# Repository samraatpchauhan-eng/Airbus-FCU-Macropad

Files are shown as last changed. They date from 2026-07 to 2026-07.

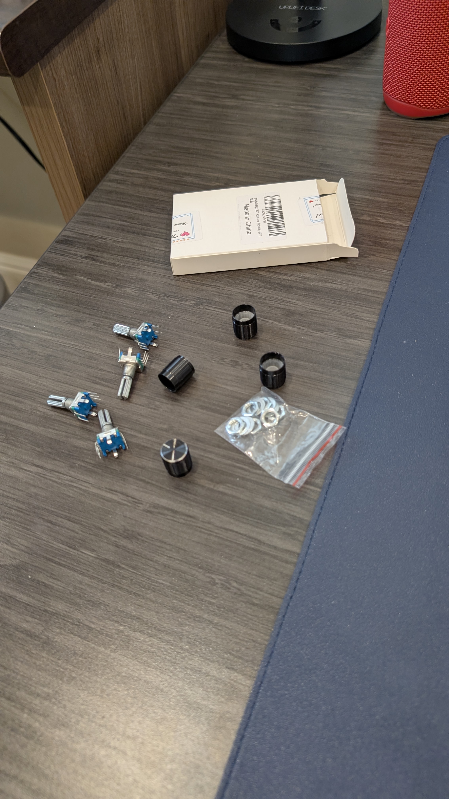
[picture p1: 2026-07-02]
Assets/PXL_20260702_192811092.jpg

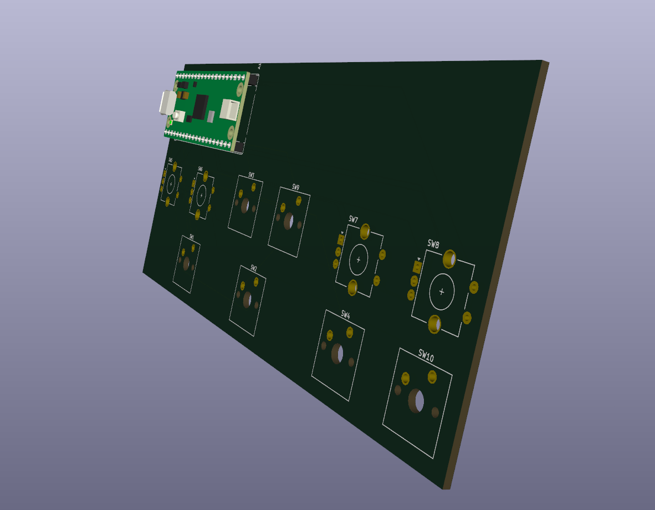
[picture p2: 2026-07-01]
Assets/Screenshot 2026-07-01 002633.png

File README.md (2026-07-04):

# Airbus FCU-Macropad

Airbus-FCU is a scaled replica of the Flight Control Unit found on Airbus aircraft, such as the Airbus A320. It is powered by a **RP Pico 1**, which has the rp2040 chip. It is used to make workflows more efficient, and to convert your desktop into a virtual cockpit! I designed it because as an aviation enthusiast, I wanted to have the ability to integrate aspects of flight and aviation in my day to day life, and I thought that instead of using a generic macropad, why not have it look like the FCU found on the airbus a320!

## Features:
* **Custom Layout:**  6 Cherry MX switches and 4 ec11 switched rotary encoders (10 Keys Total).
* **Quad Encoders:** Quad EC11 Encoders for precise, media adjustments (like brightness, zooming, or volume).
* **Realistic Design:** Engineered with a precise layout matching the real FCU found on the A320, and coordinating most commonly used inputs for an easy to use layout.
* **RP2040 Power:** Driven by the RP2040 chip for rapid response times and effortless flashing.

---

## CAD Model & Case Assembly
Everything fits together precisely using a layered enclosure design. The case includes structural mounting points for the PCB, plates, and components to ensure zero deck-flex during heavy use. Please note the keycaps used in these renders are generic .STEP models downloaded from the internet, and any standard MX keycap should work.

### Case Assembly & Fitment
*A 3D CAD visualization highlighting how the PCB, switches, encoders, and structural enclosure layers interface together seamlessly.*

Airbus-FCU-Case_2026-Jul-02_07-37-07PM-000_CustomizedView3551822146

Airbus-FCU-Case_2026-Jul-02_07-30-18PM-000_CustomizedView15151844348

---

## PCB Design
The underlying electronics were engineered in KiCad. The board features clean routing paths optimized for the RP2040 pin configurations and a direct connection layout to handle both the key switches and rotary encoders.

### Schematic Design
*The circuit schematic mapping the switch routing, and quad encoder connections to the microcontroller.*



### PCB Layout Architecture
*The routed printed circuit board design detailing trace paths, footprints, and physical alignment.*



---

## How to Flash
1. Disconnect the USB cable from the Flight Pad.
2. Press and hold the physical **BOOT** button on the RP2040 controller board.
3. Reconnect the USB cable while holding the button, then release it.
4. A virtual drive named will mount to your operating system.
5. Drag and drop the `airbus_fcu_macropad_default.uf2` binary file directly onto the root of the drive.
6. The device will automatically flash, reboot, and initialize as an operational HID keyboard device.

---

## AI Attribution Note
**Please Note that AI was utilized for some basic project planning and debugging of the Keyboard.JSON, and Keymap.C files in VS.Code**

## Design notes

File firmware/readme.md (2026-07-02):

# airbus_fcu_macropad

*A short description of the keyboard/project*

* Keyboard Maintainer: [Samraat Chauhan](https://github.com/samraatpchauhan-eng)
* Hardware Supported: *The PCBs, controllers supported*
* Hardware Availability: *Links to where you can find this hardware*

Make example for this keyboard (after setting up your build environment):

    make airbus_fcu_macropad:default

Flashing example for this keyboard:

    make airbus_fcu_macropad:default:flash

See the [build environment setup](https://docs.qmk.fm/#/getting_started_build_tools) and the [make instructions](https://docs.qmk.fm/#/getting_started_make_guide) for more information. Brand new to QMK? Start with our [Complete Newbs Guide](https://docs.qmk.fm/#/newbs).

## Bootloader

Enter the bootloader in 3 ways:

* **Bootmagic reset**: Hold down the key at (0,0) in the matrix (usually the top left key or Escape) and plug in the keyboard
* **Physical reset button**: Briefly press the button on the back of the PCB - some may have pads you must short instead
* **Keycode in layout**: Press the key mapped to `QK_BOOT` if it is available

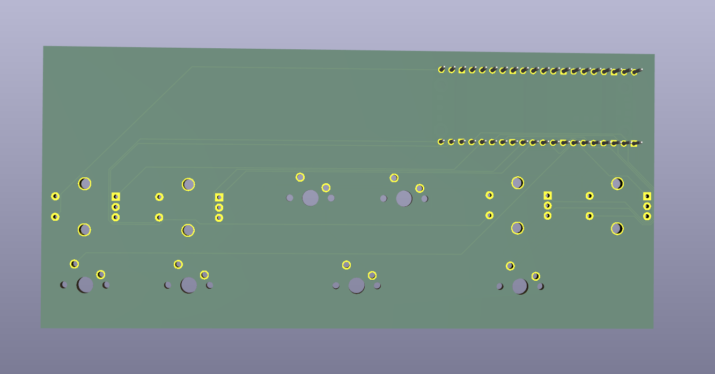
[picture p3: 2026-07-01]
Assets/Screenshot 2026-07-01 002709.png

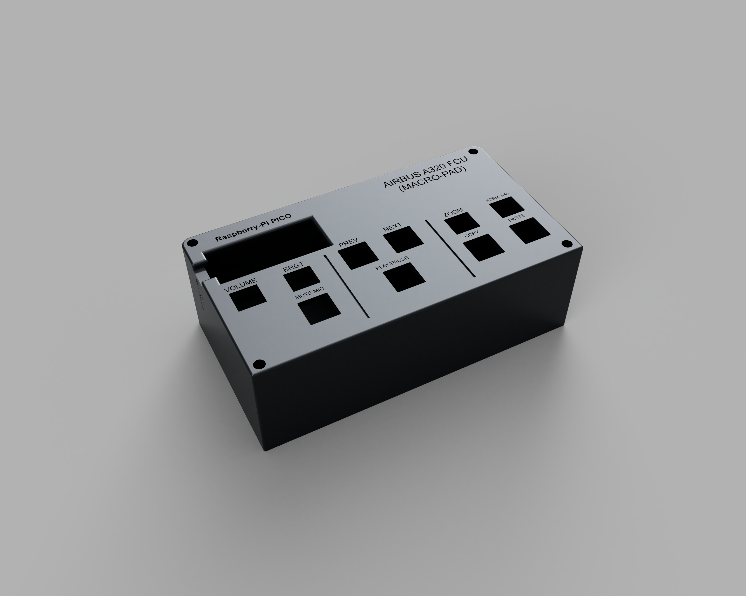
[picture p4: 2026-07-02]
Assets/Airbus-FCU-Case_2026-Jul-02_07-24-20PM-000_CustomizedView7984582045.png

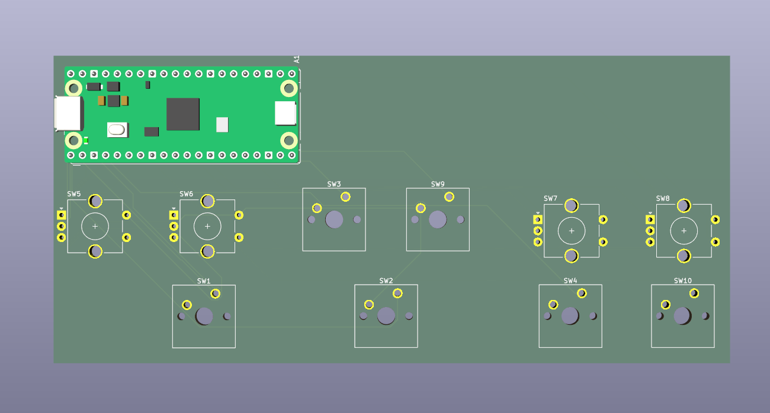
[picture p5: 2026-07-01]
Assets/Screenshot 2026-07-01 002624.png

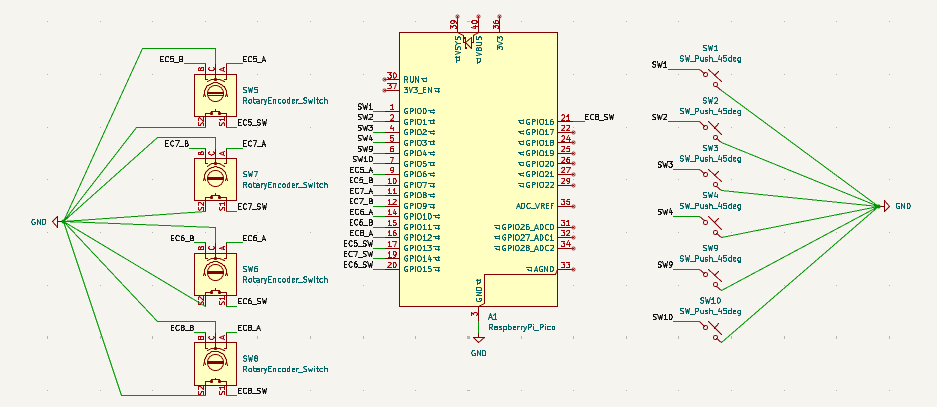
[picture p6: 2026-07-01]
Assets/Screenshot 2026-07-01 002244.png

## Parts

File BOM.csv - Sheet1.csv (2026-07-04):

Item Name | Qty | Estimated Price (total) (USD) | Item link | Notes
Raspberry Pi Pico (rp2040) with headers | 1 | $11.39 | https://www.amazon.com/waveshare-Pico-Microcontroller-Development-Pre-soldered/dp/B0912M3T1H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 | Make sure it is based on the rp2040 chip and comes with pre soldered headers to solder to the pcb
Airbus-FCU custom PCB | 1 | $9.90 | https://cart.jlcpcb.com/quote?spm=jlcpcb.Public.2006 | N/A
Cherry MX - Green | 6 | $19.50 | https://www.amazon.com/Wholesales-Authentic-Mechanical-Keyboard-Switches/dp/B07K566Q1Z?s=electronics | The lowest number of switches one can buy are 24, even though 6 are only needed
EC11 switched encoders with knobs | 4 | $8.39 | https://a.co/d/0bOTq829 | N/A
Cherry MX - Keycaps | 6 | $8.99 | https://www.amazon.com/Mechkeeb-Profile-Orange-Mechanical-Keyboard/dp/B0BWMNZ2QH | The lowest number of keycaps one can buy are 24, even though 6 are only needed
3mm screws | 4 | $5.99 | https://a.co/d/0bBv0Egk | N/A
3d Printed Case (Top and Bottom) | 1 | ~2.00 | STL files can be found in the CAD folder | Unsure about exact cost of printing, as I don't have a 3d printer for reference
Total Price (USD): | $66.16

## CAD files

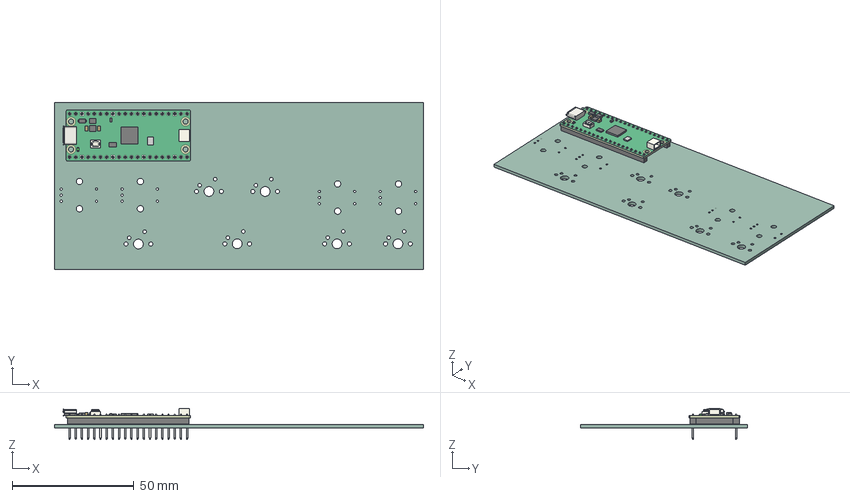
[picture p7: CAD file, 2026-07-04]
PCB/PCB.step
151.5 x 68.5 x 12.8 mm
RaspberryPi_Pico_H_Module_KiCad
RaspberryPi_Pico_Header_DIP-40_H2.54mm_KiCad
Stardance-Airbus-FCU_PCB

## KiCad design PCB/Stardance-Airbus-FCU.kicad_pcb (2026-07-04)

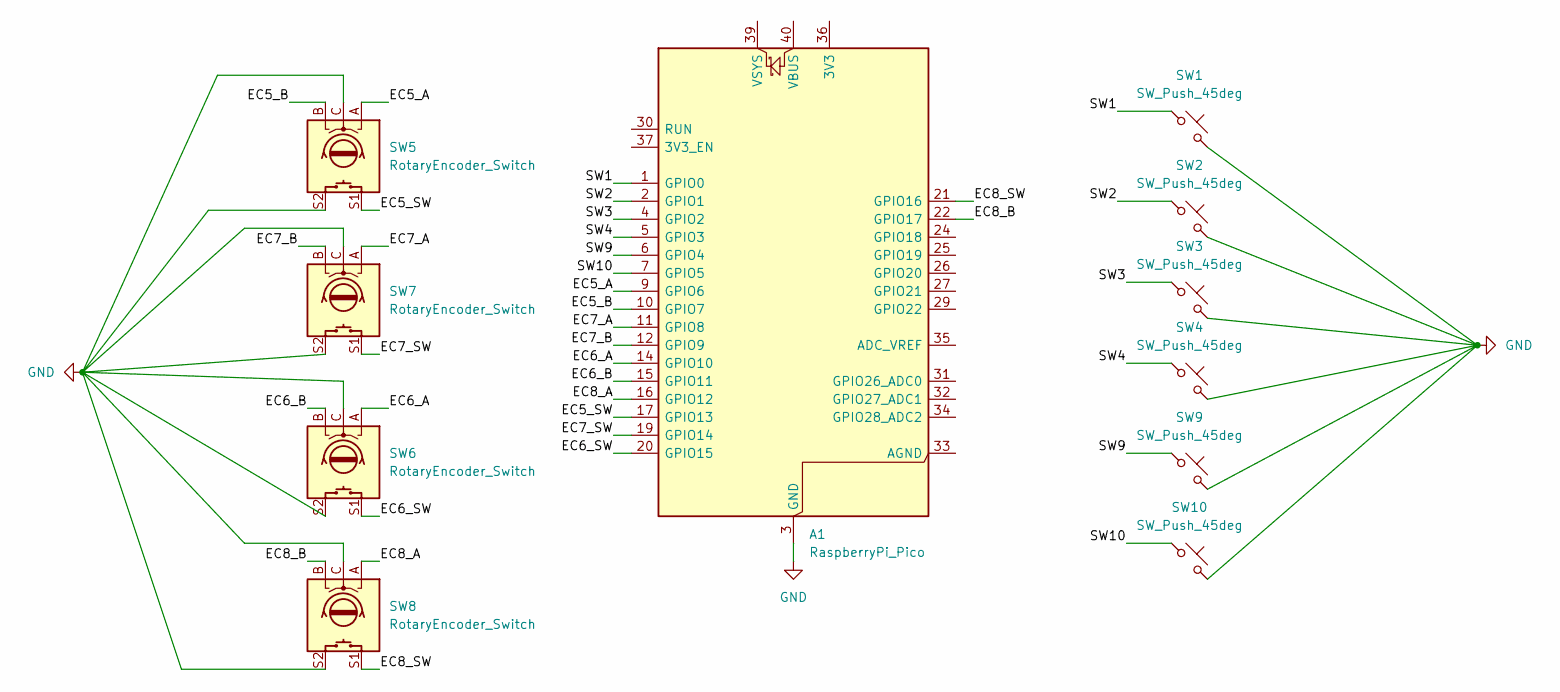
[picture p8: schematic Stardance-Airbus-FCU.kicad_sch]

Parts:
A1: RaspberryPi_Pico; RaspberryPi_Pico_Common_THT
SW1, SW2, SW3, SW4, SW9, SW10: SW_Push_45deg; SW_Cherry_MX_1.00u_PCB
SW5, SW6, SW7, SW8: RotaryEncoder_Switch; RotaryEncoder_Alps_EC11E-Switch_Vertical_H20mm_CircularMoun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

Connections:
/EC5_A: A1.9 (GPIO6), SW5.A
/EC5_B: A1.10 (GPIO7), SW5.B
/EC5_SW: A1.17 (GPIO13), SW5.S1
/EC6_A: A1.14 (GPIO10), SW6.A
/EC6_B: A1.15 (GPIO11), SW6.B
/EC6_SW: A1.20 (GPIO15), SW6.S1
/EC7_A: A1.11 (GPIO8), SW7.A
/EC7_B: A1.12 (GPIO9), SW7.B
/EC7_SW: A1.19 (GPIO14), SW7.S1
/EC8_A: A1.16 (GPIO12), SW8.A
/EC8_B: A1.22 (GPIO17), SW8.B
/EC8_SW: A1.21 (GPIO16), SW8.S1
/SW1: A1.1 (GPIO0), SW1.1
/SW2: A1.2 (GPIO1), SW2.1
/SW3: A1.4 (GPIO2), SW3.1
/SW4: A1.5 (GPIO3), SW4.1
/SW9: A1.6 (GPIO4), SW9.1
/SW10: A1.7 (GPIO5), SW10.1
GND: A1.3 (GND), A1.8 (GND), A1.13 (GND), A1.18 (GND), A1.23 (GND), A1.28 (GND), A1.38 (GND), SW1.2, SW2.2, SW3.2, SW4.2, SW5.C, SW5.S2, SW6.C, SW6.S2, SW7.C, SW7.S2, SW8.C, SW8.S2, SW9.2, SW10.2

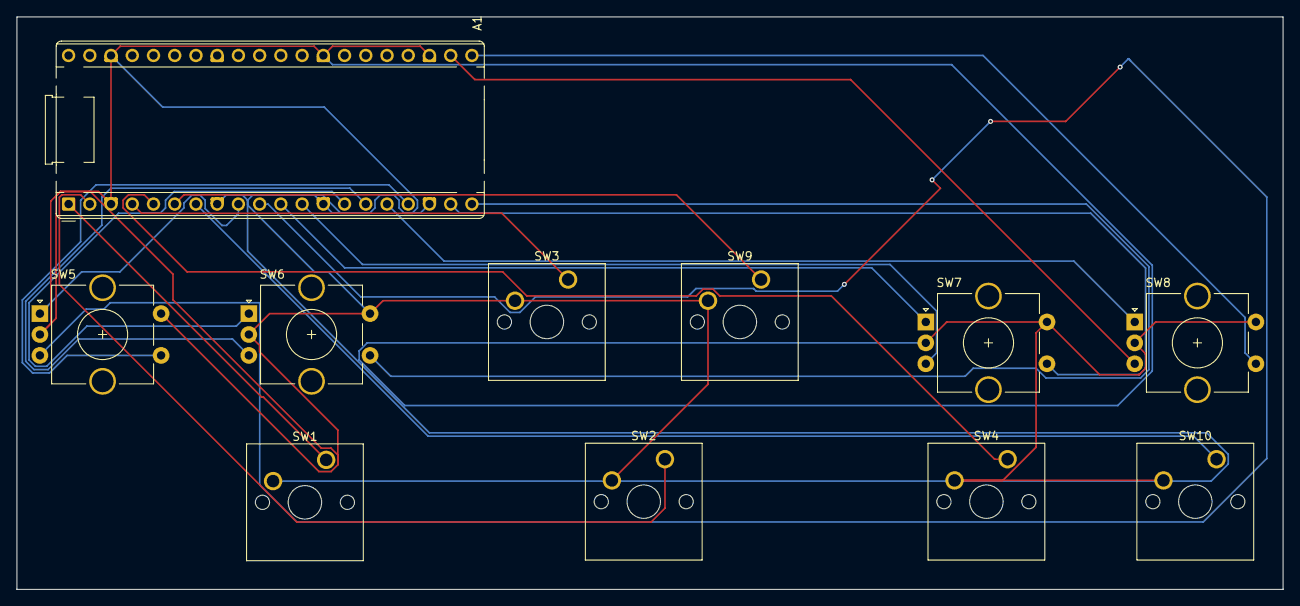
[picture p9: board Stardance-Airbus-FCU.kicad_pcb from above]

Board: 2 copper layers, 151.5 x 68.5 mm, 11 parts (0 on the bottom side), 19 nets.

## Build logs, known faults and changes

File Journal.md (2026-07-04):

- **6/28/2026**    
- Time Spent: 4 hrs 18 min
    - General Overview: Started planning out and designing the PCB for the Airbus-FCU macropad. I utilized Fly-By-Wire's extensive diagram on their website as reference, and KiCad to design the pcb. The pcb will house 4 EC11 rotary encoders with a switch, and 6 cherry MX switches, which are all powered by a RP Pico. The firmware will most likely come from QMK MSYS, or MobiFlight, and utlizing the FBW A32NX API.
    - Challenges Faced: Had to spend alot of time remapping and ensuring that all the tracks for the PCB lay out properly. I also had to factor in hardware placement, ensuring it stays accurate to the real FCU. I initially also was planning to use the Epal Arduino mega 2560 pro mini clone, but ended up going into a rabbit hole trying to find and create a custom footprint that is accurate to the real board, so I ended up using the RP Pico 1.
  
    - Media:

      Schematic Diagram
      

      PCB diagram with tracks layed out without intersection (finally lol)
      
  
      Just a couple of 3d renderings of the PCB aswell :)
      
      
      
  
      Layout of the FCU for the airbus a320 (do note I won't be including the 2 displays due to the RP Pico limitations, and space in the case)
      
<hr background color: #FFFFFF>

- ** 6/29/2026**
    - Time Spent: 5 hrs
    - General Overview: This was probably one of the harder, more creative days. I spent tody mainly formulating a case design, and how all the hardware will fit inside it. I also took today to conceptualize the function of each switch and encoder if it were to be used outside the flight sim, as a regular macropad. I decided to assign the rotary encoders to the following:
      
      - Volume / Mute Toggle
      - Brightness / Sleep PC
      - Zoom In-Out / Reset Zoom
      - Horizontal Nav & Scrolling / Pause or Play Toggle
        
    - And I decided to assign the buttons to the following:
      
      - Mute Mic
      - Media Next Track
      - Media Previous Track
      - Pause / Play Toggle
      - Undo
      - Redo
        
    - Challenges Faced: The hardest part of today was definitely figuring out the function of each input device, aswell as accurately mapping out each hole cutout for the top plate in Autodesk Fusion360 (goated CAD program btw). It was also pretty difficult getting the RP pico to fit in the case as I decided to leave a hole cutout to be able to view the board from the outside. I would say I spent the most time troubleshooting the physical fitment of the pcb, input devices and case design together.
    - Media:

      This is basically how the layout will work for the top plate, with the nice addition of a clear view of the RP Pico, with a neat engraving on top
      
 
      This is the bottom section of the case. It's currently a plain box, but overtime I do plan to refine it into something more complete, and refined
      
<hr background color: #FFFFFF>

 - **6/30/2026**
    - Time Spent: 2 hrs 24 min
    - General Overview: I decided to take today a little bit easy today, to avoid stressing out and losing my sanity from yesterday's design session. I researched alot upon how MobiFlight works with Microsoft Flight Simulator 2020 (this is the sim I have currently), and the process to develop firmware and flash it onto the RP board. I also went over QMK's API to gather which keystrokes to use. I also decided to utlize VS.Code as my text editor, as I'm most familiar with it, and it works well with Hackatime.
    - Challenges Faced: Not many, however I had to get used to MobiFlight's refreshed user interface. They moved away from the traditional text editor style, and towards a more user friendly mouse pointer interactive UI.
  
    - Media:
      The new and improved UI for MobiFlight did introduce a bit of a learning curve, as they changed out alot of thing, such as where you can add boards, and the process of adding inputs and outputs
      
  
      This is a general overview of the keybinds and keycodes. I did change the Undo and Redo buttons to Copy Paste, as that is more commonly used
      
<hr background color: #FFFFFF>

- **7/1/2026**
    - Time Spent: 3 hrs 45 min
    - General Overview: I jumped back into the grind today, but wasn't able to send too much time as I had a dentist appointment aswell. I did however finish up polishing the design of the case, and was able to get it looking complete, with nice rounded edges, and neat engravings to label each input device. I also started developing the firmware for the FCU, by utlizing QMK MSYS and VS.Code. I finished up the keyboard.json file, but am yet to complete the keymap.c file, as that will require careful matching, and good focus. I decided to hold that off for tomorrow morning.
    - Challenges Faced: I made quiet a stupid mistake. As I was writing up the json file for the FCU firmware, I realized I had completely forgotten to map the "b" pin for one of the rotary encoders. I had to go back into KiCad, and a) Wire up the b pin to a digital pin on the board; and b) re-layout all the tracks in the PCB editor to account for the missing connection. I also faced a problem when creating the engravings in Fusion360. I tried to used the extrude tool to engrave the text which was made out of a "sketch" however the font I wanted to use had too many overlaps and gave geometry errors. I ended up going with a simpler font, to compensate.
  
    - Media:

      This is the finalized design for the case. I'm really happy with how it turned out, as it's detailed while maintaining a minimal asthetic that I always dig, and had nice subtle round edges all around
      
      
      
      Due to my laziness :) I had to go back and add the extra connection for EC8_B, and revise the track layout for the actual PCB 
      
      
<hr background color: #FFFFFF>

 - **7/2/2026**
    - Time Spent: 3 hrs 18 min
    - General Overview: Last day! I spend today finalizing the case, and writing up the rest of my firmware, and compiling it to get the .uf2 file. I also spent alot of time gathering screenshots, data, and cad/pcb exports to put into my git repo. I also wrote up my .readme file, and obviously this journal entry. Thankfully I did have a few parts in my spare electronics bin to visualize what it could look like.
    - Challenges Faced: There weren't many challenges today, except for some errors I encountered when compiling the firmware, as I kept using what I thought was the correct keycode naming scheme for horizontal scrolling, but I was able to fix it later on.
  
    - Media:

      Final Airbus-FCU render
      Airbus-FCU-Case_2026-Jul-02_07-37-07PM-000_CustomizedView3551822146
   
      Case Design
      Airbus-FCU-Case_2026-Jul-02_07-24-20PM-000_CustomizedView7984582045
  
      Was able to find 4 ec11 encoders with knobs! :)
      

      :( ugh the dreaded errors.........
      
<hr background color: #FFFFFF>

TOTAL TIME SPENT ON THIS PROJECT: **18 Hours, 45 Minutes**

<hr background color: #FFFFFF>

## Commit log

2026-07-01 Document progress on case design and hardware layout
    Added detailed entries for 6/29/2026, including time spent, general overview, challenges faced, and media related to the case design and hardware layout.
2026-07-02 Added renders of final case design
2026-07-02 Added gerbers file and pcb files
    [Stardance-Airbus-FCU.kicad_pcb, Stardance-Airbus-FCU.kicad_sch]
2026-07-02 Added 3d printing files and BOM
    [Airbus-FCU-Case-BOTTOM.stl, Airbus-FCU-Case-TOP.stl]
2026-07-02 Add PCB layout architecture section to README
2026-07-02 Finalize case design and complete firmware
    Finalized the case design and completed firmware development for the Airbus-FCU macropad. Compiled firmware into .uf2 file and documented project details.
2026-07-04 revision 1 file uploads
    [Airbus-FCU-Case-BOTTOM.stl, Airbus-FCU-Case-TOP.stl, PCB.step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]
2026-07-04 Revised PCB
    [PCB.step, Stardance-Airbus-FCU.kicad_pcb]
2026-07-04 changed BOM file format
    [BOM.csv]
2026-07-04 Revise PCB image and AI attribution in README
    Updated PCB layout image and modified AI attribution note for clarity.
2026-07-04 Finalize case design and complete firmware development
    Finalized the case design and completed firmware development for the Airbus-FCU macropad. Compiled the firmware into a .uf2 file and updated project documentation.
2026-07-04 fixed BOM links
    [BOM.csv, BOM.csv - Sheet1.csv]
